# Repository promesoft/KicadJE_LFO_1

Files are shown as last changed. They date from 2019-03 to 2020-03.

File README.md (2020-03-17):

# Johansen Engineering KiCadJE_LFO_1.2 (Rev B)

Analogue LFO - minor adjustments - new jacks (PJ321 -> pj324) - remove Sine Adj

555 Based LFO - minor adjustments - new jacks (PJ321 -> pj324) - remove XXX

NAND - Footprint adj

# Purpose
Fix issues with RevA

## 555 LFO
+/- 10V LFO Square, Triangle, Sine

2 frequency ranges

## LFO
+/- 10V LFO Square, Triangle, Sine

## NAND
NOT Gate (pull dn) - NAND Gate (both pull up) - AND Gate (both pull up)

0-10V output - CMOS input

## D-Flip Flop
0-10V output - CMOS input

## MMX
+-10V Input/output - DC couple

Top - 3 input mixer with phase reversal

Bottom - 3 mult output with phase reversal - uses mixer output as input if not applied to mult input

# Status - In the mail
## Initial 
| Stage  | Detail | Status |
| --- | --- | --- |
| create material  | sch/pcb | OK  |
| | gerber | OK |
| production  | | OK |
|  | produced | Yes |
|  | delivered | OK |

## Preliminary validation
| Test  | Detail | Status |
| --- | --- | --- |
| Initial Inspection | | OK |
| Initial Technical Test | LFO555 |  |
| | | PJ321 should be 1 mm further from the front, center tap works - minor footprint twist in pj324|
| Initial Technical Test | NAND |  |
| | | cut power plane and add 20k across to fix not blowing other units due to hard pull up on tip.
| Initial Product Test | LFO |  |
| Initial Product Test | LFO555 | Sine and Tri not working - needs ac coupling from square - needs dc compensation |
| Initial Product Test | MMX2 | |
| Initial Product Test | NAND | Now working with 4093 - needs pull up resistors and I/O protection |
| Initial Product Test | FlipFlop |  |

## Secondary validation
| Test  | Detail | Status |
| --- | --- |--- |
| Product Test | LFO | |
| Product Test | LFO555 | working right - tri and sine needs tweaking of waveforms |
| Product Test | MMX2 |  |
| Product Test | NAND | working - see issues |
| Product Test | FlipFlop | Working as intended except for LED's |
| Quality | LFO | |
| Quality | LFO555 | |
| Quality | MMX2 | |
| Quality | NAND |  |
| Quality | FlipFlop | |
| Long Term Product Test |  |  |
| Power Draw |  | 

## Errata
### Errata - LFO

### Errata - LFO555

### Errata - MMX2

### Errata - Flip-Flop

### Errata - NAND
Hard pull up to 12 can fry other units !!! Add resistor pull up

Output protection (series resistor?)

## Issues and Notes
### LFO

### 555 LFO
AC coupling of Square should be considered - internal and at least DC adj external

bias current compensation (eg. 10k to GND)

### Flip-Flop

### MMX2
### NAND

# Pictures
## MMX2
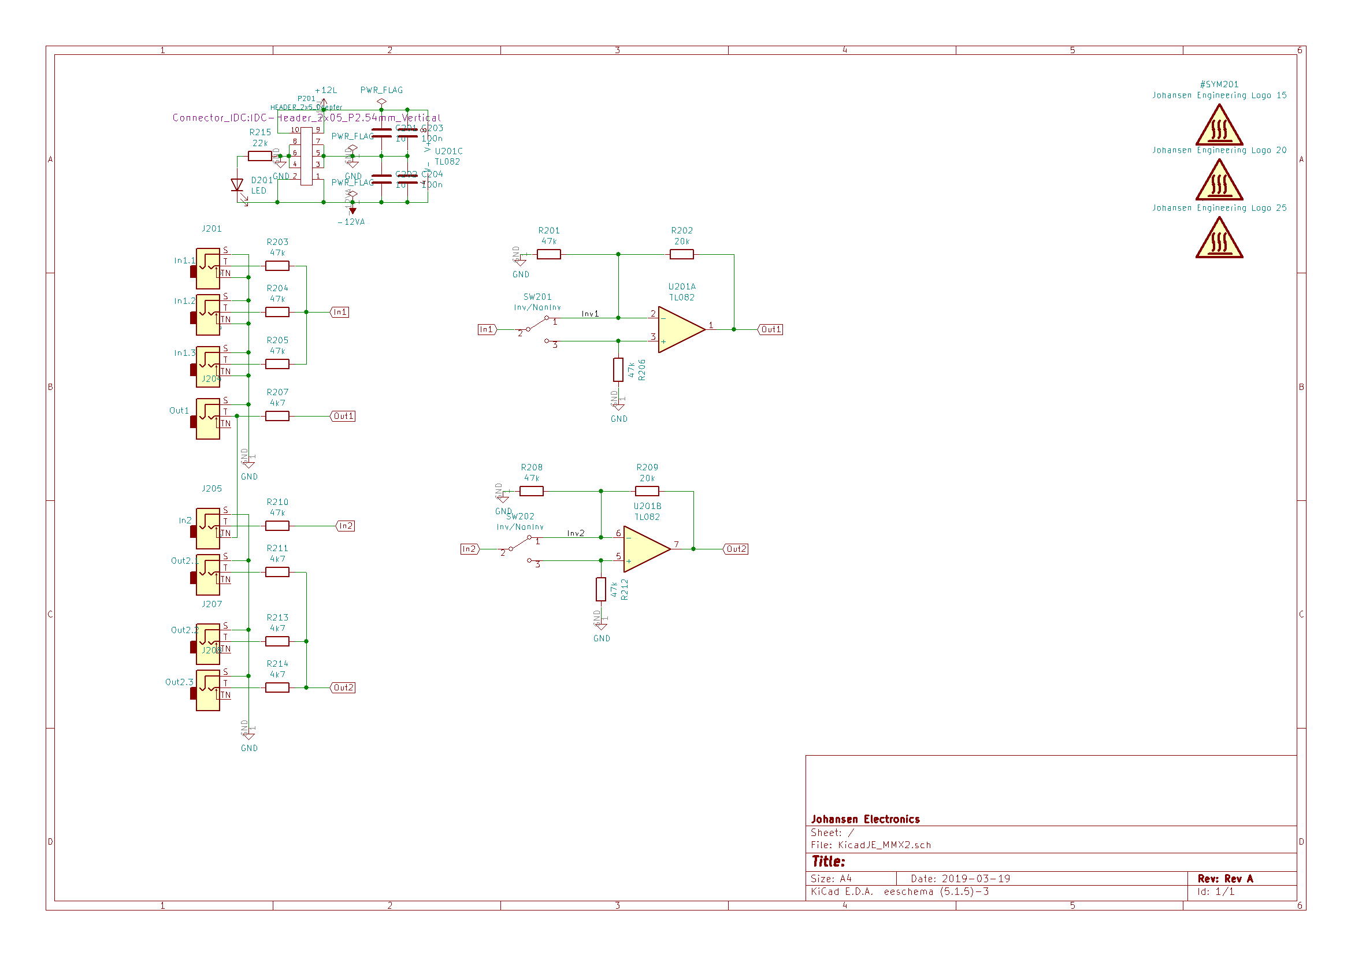
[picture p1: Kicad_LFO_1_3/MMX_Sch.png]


------------------------------------------------
# Johansen Engineering KiCadJE_LFO_1
Initial Analogue LFO

# Purpose

# Status - Evaluated
## Initial 
| Stage  | Detail | Status |
| --- | --- | --- |
| create material  | sch/pcb | OK  |
| | gerber | OK |
| production  | | OK |
|  | produced | Yes |
|  | delivered | Yes |
## Preliminary validation
| Test  | Detail | Status |
| --- | --- | --- |
| Initial Inspection | | OK |
| Initial Technical Test | LFO555 | 555 and 072 gets warm in certain settings |
| Initial Product Test | LFO | Works well with R311 not mounted |
| | | Pot's should be 1 mm closer to front (or jacks further back)|
| Initial Product Test | LFO555 | Sine and Tri not working - RV101B should have 500R series resistor |
| Initial Product Test | MMX2 | Works nicely |
| Initial Product Test | NAND | Not working with 4093 - footprint matches 74HC00 |
| Initial Product Test | FlipFlop | Working |

## Secondary validation
| Test  | Detail | Status |
| --- | --- |--- |
| Product Test | LFO | |
| Product Test | LFO555 | not working right |
| Product Test | MMX2 | Working as intended |
| Product Test | NAND | Will Never work |
| Product Test | FlipFlop | Working as intended except for LED's |
| Quality | LFO | Sounds nice - a few constraints on pot's would be nice|
| Quality | LFO555 | |
| Quality | MMX2 | |
| Quality | NAND | Will Never work |
| Quality | FlipFlop | |
| Long Term Product Test |  |  |
| Power Draw |  | 

## Errata
### Errata - LFO555
1 - SW101 too close to P101
### Errata - MMX2
1 - 1206 caps (C201+C202) are too close to the switch to mount both
### Errata - Flip-Flop
1 - LED positions swapped
### Errata - NAND
Will Never work - Footprint wrong so Input is directly coupled to output for some NAND's

## Issues and Notes
### LFO
1 - 100k should not be mounted (it ruins feedback)

2 - Sine pot should have 2k series resistor

3 - C303 could be 100nF and 1uF addon with a switch for high low

4 - Frequency pot is sensitive at low freq

5 - Chose different Jacks

6 - Consider adding series resistor to outputs

7 - mounting holes

8 - Pot's should be 1 mm closer to front (or jacks further back)

### 555 LFO
1 - RV101B should have series resistor (330 - 1k)

2 - All outputs should have a series resistor (470R ?)

3 - Pot's should be 1 mm closer to front (or jacks further back)

4 - RV101 footprint not matching pots

### Flip-Flop
1 - LED positions swapped

### NAND
Will Never work - Footprint wrong so Input is directly coupled to output for some NAND's

# Pictures
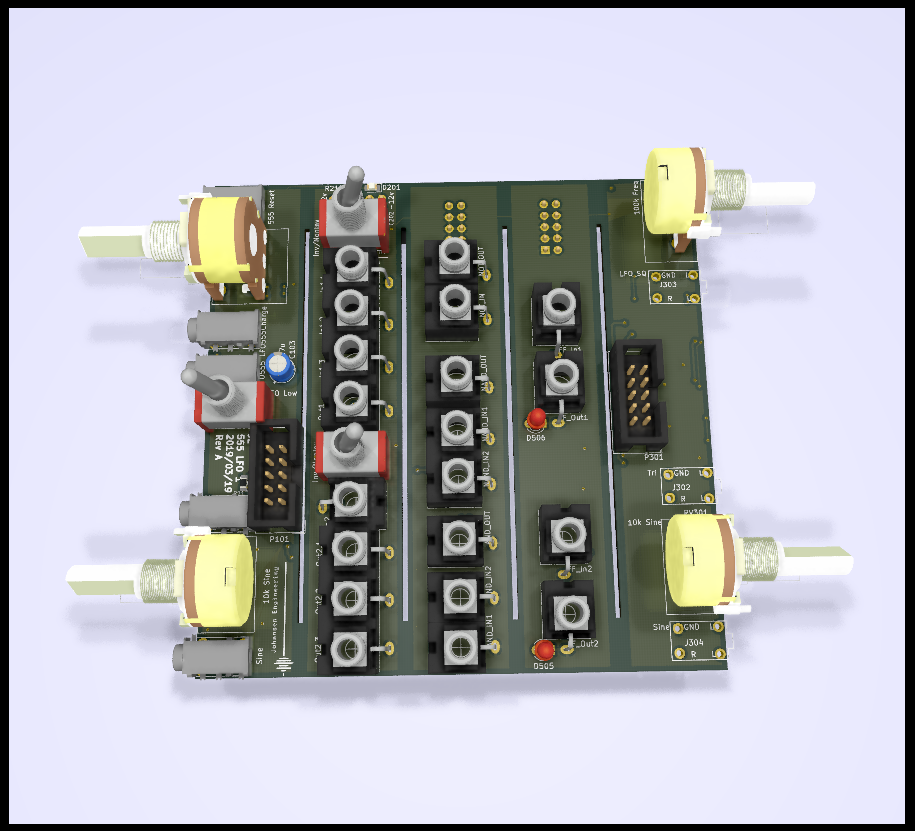
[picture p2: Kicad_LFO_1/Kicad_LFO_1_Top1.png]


# Inspiration from 
https://www.electronics-tutorials.ws/waveforms/555_oscillator.html

http://electro-music.com/forum/topic-31166.html

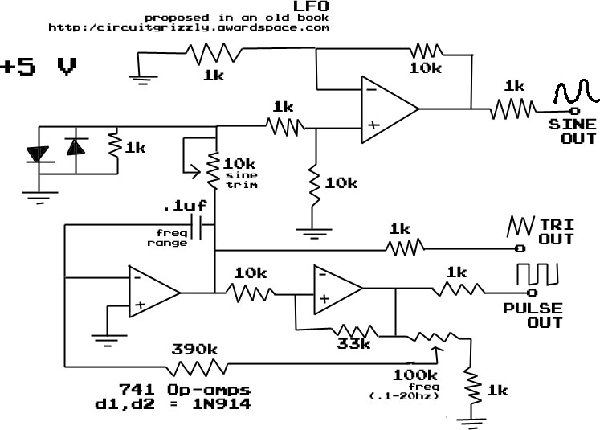
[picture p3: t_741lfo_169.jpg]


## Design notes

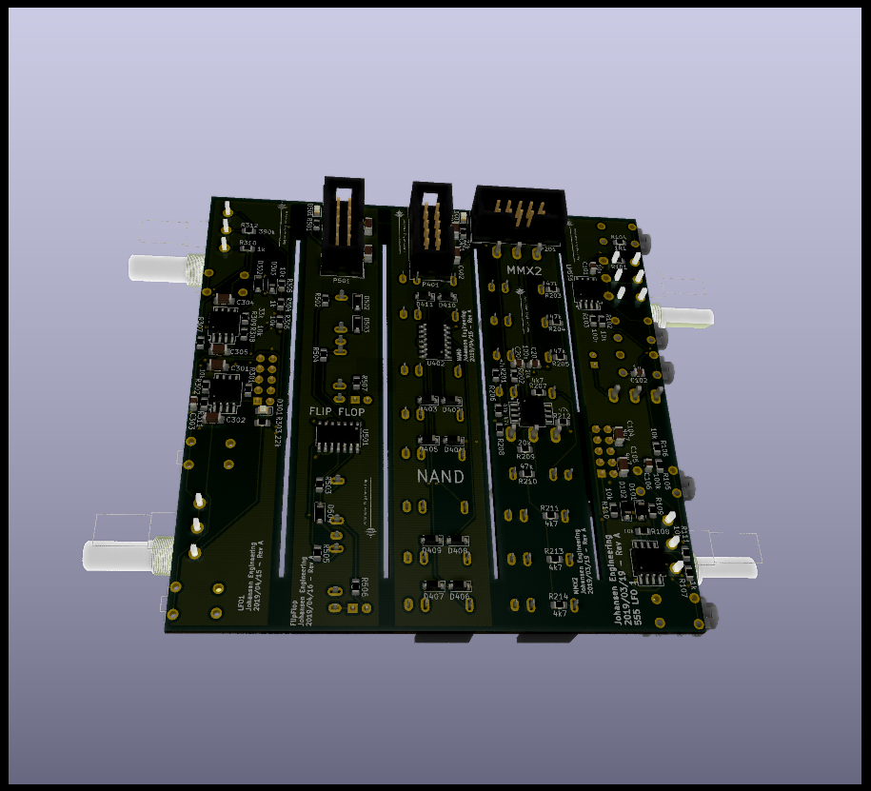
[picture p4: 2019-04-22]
Kicad_LFO_1/Kicad_LFO_1_Bottom1.png

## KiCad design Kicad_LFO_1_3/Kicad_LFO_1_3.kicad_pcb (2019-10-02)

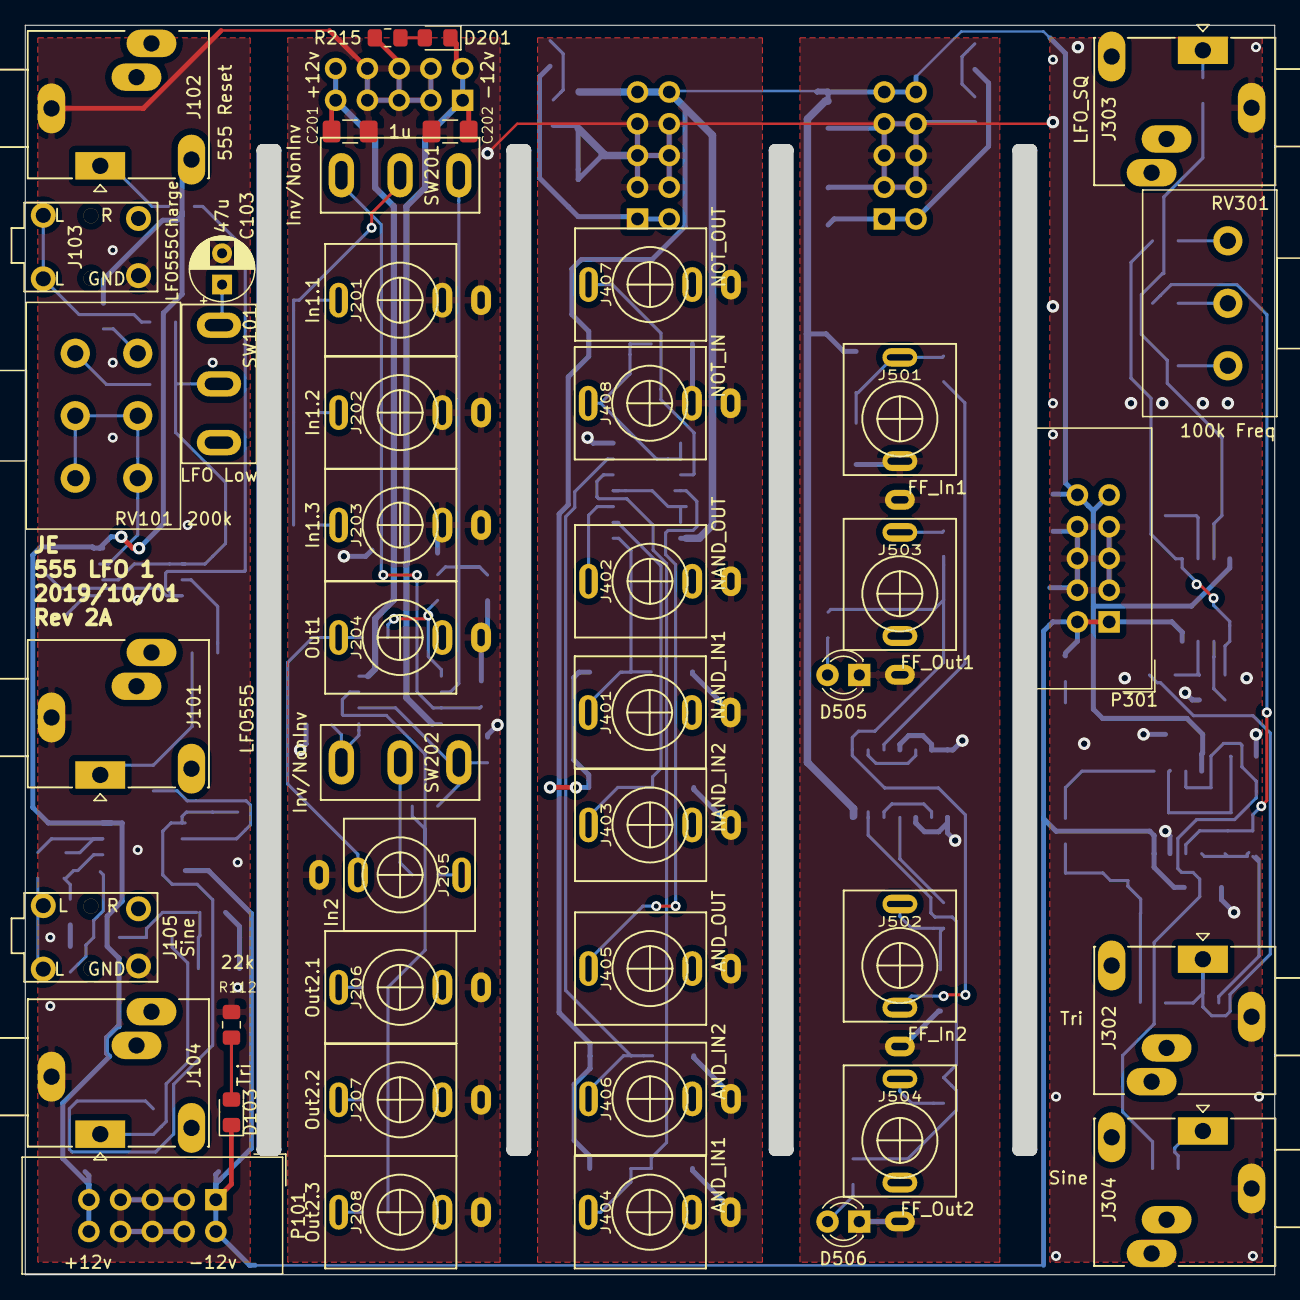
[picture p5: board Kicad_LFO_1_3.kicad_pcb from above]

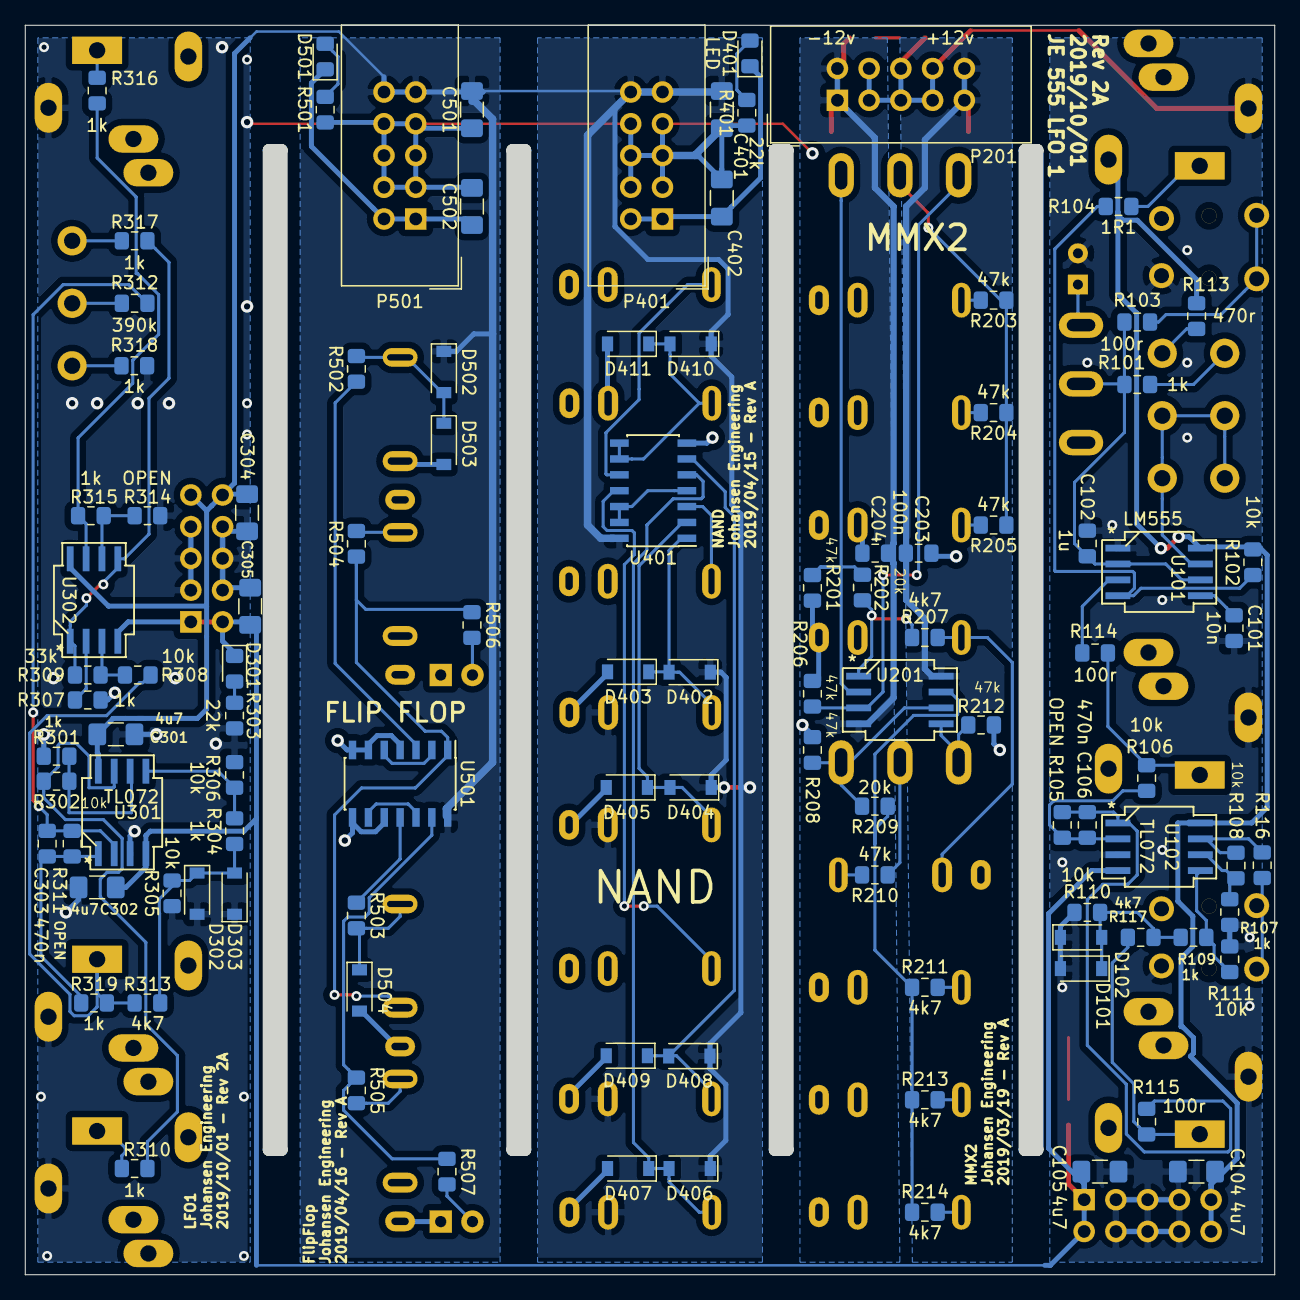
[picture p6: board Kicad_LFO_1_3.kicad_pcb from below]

Board: 2 copper layers, 100.0 x 100.0 mm, 147 parts (103 on the bottom side), 83 nets.

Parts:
C101: 10n; C_0805_2012Metric_Pad1.15x1.40mm_HandSolder
C102: 1u; C_0805_2012Metric_Pad1.15x1.40mm_HandSolder
C103: 47u; CP_Radial_D5.0mm_P2.50mm
C104, C105, C301, C302, C401, C402, C501, C502: 4u7; C_1206_3216Metric_Pad1.42x1.75mm_HandSolder
C106, C303: 470n; C_0805_2012Metric_Pad1.15x1.40mm_HandSolder
C201, C202: 1u; C_1206_3216Metric_Pad1.42x1.75mm_HandSolder
C203, C204: 100n; C_0805_2012Metric_Pad1.15x1.40mm_HandSolder
C304, C305: 100n; C_1206_3216Metric_Pad1.42x1.75mm_HandSolder
D101, D102, D302, D303: 1N4148W; D_SOD-123
D103, D201, D301, D401, D501: LED; LED_0805_2012Metric_Pad1.15x1.40mm_HandSolder
D402, D403, D404, D405, D406, D407, D408, D409, D410, D411, D502, D503, D504: MRA4007T3G; D_SOD-123
D505: LEDOut1; LED_D3.0mm
D506: LEDOut2; LED_D3.0mm
J101: LFO555; Jack_3.5mm_Ledino_KB3SPRS_Horizontal
J102: 555 Reset; Jack_3.5mm_Ledino_KB3SPRS_Horizontal
J103: LFO555Charge; AudioJack3StereoNarrow-PJ-321
J104, J302: Tri; Jack_3.5mm_Ledino_KB3SPRS_Horizontal
J105: Sine; AudioJack3StereoNarrow-PJ-321
J201: In1.1; PJ301SM
J202: In1.2; PJ301SM
J203: In1.3; PJ301SM
J204: Out1; PJ301SM
J205: In2; PJ301SM
J206: Out2.1; PJ301SM
J207: Out2.2; PJ301SM
J208: Out2.3; PJ301SM
J303: LFO_SQ; Jack_3.5mm_Ledino_KB3SPRS_Horizontal
J304: Sine; Jack_3.5mm_Ledino_KB3SPRS_Horizontal
J401: NAND_IN1; PJ301SM
J402: NAND_OUT; PJ301SM
J403: NAND_IN2; PJ301SM
J404: AND_IN1; PJ301SM
J405: AND_OUT; PJ301SM
J406: AND_IN2; PJ301SM
J407: NOT_OUT; PJ301SM
J408: NOT_IN; PJ301SM
J501: FF_In1; PJ301SM
J502: FF_In2; PJ301SM
J503: FF_Out1; PJ301SM
J504: FF_Out2; PJ301SM
P101, P201, P301, P401, P501: HEADER_2x5_Doepfer; IDC-Header_2x05_P2.54mm_Vertical
R101, R107, R109, R301, R304, R307, R310, R315, R316, R317, R318, R319: 1k; R_0805_2012Metric_Pad1.15x1.40mm_HandSolder
R102, R106, R108, R110, R111, R302, R305, R306, R308: 10k; R_0805_2012Metric_Pad1.15x1.40mm_HandSolder
R103, R114, R115, R116: 100r; R_0805_2012Metric_Pad1.15x1.40mm_HandSolder
R104: 1R1; R_0805_2012Metric_Pad1.15x1.40mm_HandSolder
R105, R311, R314: OPEN; R_0805_2012Metric_Pad1.15x1.40mm_HandSolder
R112, R215, R303, R401, R501, R506, R507: 22k; R_0805_2012Metric_Pad1.15x1.40mm_HandSolder
R113: 470r; R_0805_2012Metric_Pad1.15x1.40mm_HandSolder
R117, R207, R211, R213, R214, R313, R502, R503, R504, R505: 4k7; R_0805_2012Metric_Pad1.15x1.40mm_HandSolder
R201, R203, R204, R205, R206, R208, R210, R212: 47k; R_0805_2012Metric_Pad1.15x1.40mm_HandSolder
R202, R209: 20k; R_0805_2012Metric_Pad1.15x1.40mm_HandSolder
R309: 33k; R_0805_2012Metric_Pad1.15x1.40mm_HandSolder
R312: 390k; R_0805_2012Metric_Pad1.15x1.40mm_HandSolder
RV101: 200k; Potentiometer_Alps_RK163_Dual_Horizontal
RV301: 100k Freq; Potentiometer_Alps_RK163_Single_Horizontal
SW101: LFO Low; SP1MS1
SW201, SW202: Inv/NonInv; SP1MS1
U101: LM555; AJ_SO-8_5.3x6.2mm_P1.27mm
U102, U301, U302: TL072; AJ_SO-8_5.3x6.2mm_P1.27mm
U201: TL082; AJ_SO-8_5.3x6.2mm_P1.27mm
U401: 4011; SOIC-14_3.9x8.7mm_P1.27mm
U501: 4013; SOIC-14_3.9x8.7mm_P1.27mm

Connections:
+12L: C201.1, C203.1, P201.9, P201.10, U201.8
+12V: C104.2, C301.2, C304.2, C401.2, C501.2, D402.1, D404.1, D406.1, D408.1, D410.1, D502.1, J102.TN, J401.TN, J403.TN, J404.TN, J406.TN, P101.9, P101.10, P301.9, P301.10, P401.9, P401.10, P501.9, P501.10, R102.2, R113.2, U101.8, U102.8, U301.8, U302.8, U401.14, U501.14
-12V: C105.1, C302.1, C305.1, C402.1, C502.1, D103.1, D301.1, D401.1, D501.1, P101.1, P101.2, P301.1, P301.2, P401.1, P401.2, P501.1, P501.2, U102.4, U301.4, U302.4
-12VA: C202.2, C204.2, D201.1, P201.1, P201.2, U201.4
/KicadJE_MMX2/Inv1: R201.1, R202.2, SW201.1, U201.2
/KicadJE_MMX2/Inv2: R208.1, R209.2, SW202.1, U201.6
AND_IN1: D406.2, D407.1, J404.T, U401.5
AND_IN2: D408.2, D409.1, J406.T, U401.6
Charge: J103.T, R103.1
FF_IN1: R502.1, U501.3
FF_IN2: R503.1, U501.11
FF_OUT1: J502.TN, R504.1, R506.1, U501.1
FF_OUT2: R505.1, R507.1, U501.13
GND: C101.2, C102.2, C103.2, C104.1, C105.2, C201.2, C202.1, C203.2, C204.1, C301.1, C302.2, C304.1, C305.2, C401.1, C402.2, C501.1, C502.2, D101.2, D102.1, D302.2, D303.1, D403.2, D405.2, D407.2, D409.2, D411.2, D503.2, D504.2, D505.1, D506.1, J101.S, J102.S, J103.S, J104.S, J105.S, J201.S, J201.TN, J202.S, J202.TN, J203.S, J203.TN, J204.S, J205.S, J206.S, J207.S, J208.S, J302.S, J303.S, J304.S, J401.S, J402.S, J403.S, J404.S, J405.S, J406.S, J407.S, J408.S, J408.TN, J501.S, J501.TN, J502.S, J503.S, J504.S, P101.3, P101.4, P101.5, P101.6, P101.7, P101.8, P201.3, P201.4, P201.5, P201.6, P201.7, P201.8, P301.3, P301.4, P301.5, P301.6, P301.7, P301.8, P401.3, P401.4, P401.5, P401.6, P401.7, P401.8, P501.3, P501.4, P501.5, P501.6, P501.7, P501.8, R107.1, R110.1, R111.1, R112.1, R201.2, R206.1, R208.2, R212.1, R215.1, R301.1, R303.1, R305.1, R306.1, R307.1, R314.1, R318.2, R401.1, R501.1, U101.1, U102.3, U301.3, U401.7, U501.4, U501.6, U501.7, U501.8, U501.10
In1: R203.1, R204.1, R205.1, SW201.2
In2: R210.1, SW202.2
NAND_IN1: D402.2, D403.1, J401.T, U401.1
NAND_IN2: D404.2, D405.1, J403.T, U401.2
NOT_IN: D410.2, D411.1, J408.T, U401.8, U401.9
unnamed: C101.1, U101.5
unnamed: C102.1, R101.2, R103.2, SW101.2, U101.2, U101.6
unnamed: C103.1, SW101.3
unnamed: C106.1, R105.2, R115.2, U102.1
unnamed: C106.2, R105.1, R106.2, U102.2
unnamed: C303.1, R311.2, R319.1, U301.1
unnamed: C303.2, R311.1, R312.2, U301.2
unnamed: D101.1, D102.2, R109.1, R110.2, R117.2
unnamed: D103.2, R112.2
unnamed: D201.2, R215.2
unnamed: D301.2, R303.2
unnamed: D302.1, D303.2, R304.1, R305.2, R313.2
unnamed: D401.2, R401.2
unnamed: D501.2, R501.2
unnamed: D502.2, D503.1, J501.T, R502.2
unnamed: D504.1, J502.T, R503.2
unnamed: D505.2, R506.2
unnamed: D506.2, R507.2
unnamed: J201.T, R203.2
unnamed: J202.T, R204.2
unnamed: J203.T, R205.2
unnamed: J204.T, J205.TN, R207.2
unnamed: J205.T, R210.2
unnamed: J206.T, R211.2
unnamed: J207.T, R213.2
unnamed: J208.T, R214.2
unnamed: J402.T, U401.3
unnamed: J405.T, U401.11
unnamed: J407.T, U401.10
unnamed: J503.T, R504.2
unnamed: J504.T, R505.2
unnamed: R101.1, RV101.1
unnamed: R102.1, R104.1, U101.4
unnamed: R107.2, R108.1, U102.6
unnamed: R108.2, R116.2, U102.7
unnamed: R109.2, R111.2, U102.5
unnamed: R113.1, RV101.4
unnamed: R114.2, U101.3
unnamed: R206.2, SW201.3, U201.3
unnamed: R212.2, SW202.3, U201.5
unnamed: R301.2, R302.1, U301.6
unnamed: R302.2, R310.1, U301.7
unnamed: R304.2, R306.2, U301.5
unnamed: R307.2, U302.2
unnamed: R308.2, R309.1, U302.3
unnamed: R309.2, R317.1, U302.1, U302.5
unnamed: R314.2, R315.1, U302.6
unnamed: R315.2, R316.1, U302.7
unnamed: R317.2, RV301.3
unnamed: R318.1, RV301.1
unnamed: RV101.2, RV101.3, RV101.5, RV101.6, U101.7
unnamed: U401.4, U401.12, U401.13
unnamed: U501.2, U501.5
unnamed: U501.9, U501.12
Out1: R202.1, R207.1, U201.1
Out2: R209.1, R211.1, R213.1, R214.1, U201.7
Reset: J102.T, R104.2
Sine: J105.T, R116.1
Sine3: J304.T, R310.2
Square: J101.T, R106.1, R114.1
Square3: J303.T, R316.2
Square3fb: R312.1, RV301.2
Tri: J104.T, R115.1, R117.1
Tri3: J302.T, R308.1, R313.1, R319.2

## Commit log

2019-03-16 Inspiration and upd SCH 555
    [_saved_Kicad_LFO_1.sch]
2019-03-18 Init PCB
    [Kicad_LFO_1.kicad_pcb, Kicad_LFO_1.sch, _saved_Kicad_LFO_1.sch]
2019-03-18 Op amp and IDC power
    [Kicad_LFO_1.sch]
2019-03-18 Sine and tri integrator added
    [Kicad_LFO_1.kicad_pcb, Kicad_LFO_1.sch]
2019-03-18 Update Kicad_LFO_1.sch
    footprints and caps
    [Kicad_LFO_1.sch]
2019-03-19 Routed 555 LFO
    [Kicad_LFO_1.kicad_pcb]
2019-03-19 Update Kicad_LFO_1.kicad_pcb
    3D
    [Kicad_LFO_1.kicad_pcb]
2019-03-19 PCB bottom layer Vcc
    [Kicad_LFO_1.kicad_pcb]
2019-03-19 Power LED and MMX2
    [KicadJE_MMX2.sch, Kicad_LFO_1.sch]
2019-03-19 sheet naming
    [KicadJE_MMX2.sch, Kicad_LFO_1.sch]
2019-03-19 2x GND on MMX2
    [KicadJE_MMX2.sch]
2019-03-19 Power settings + Inv net
    [Kicad_LFO_1.kicad_pcb]
2019-03-19 cleanup and decoupl
    [KicadJE_MMX2.sch, Kicad_LFO_1.kicad_pcb]
2019-03-19 Logo - again
    [Kicad_LFO_1.kicad_pcb, _saved_KicadJE_MMX2.sch]
2019-03-19 MMX2 upd
    [KicadJE_MMX2.sch, _saved_KicadJE_MMX2.sch]
2019-03-20 OpAmp LFO added
    [KicadJE_072LFO.sch, KicadJE_MMX2.sch, Kicad_LFO_1.sch]
2019-03-21 TL072 LFO on PCB
    [KicadJE_072LFO.sch, Kicad_LFO_1.kicad_pcb]
2019-04-15 Diode protection
    [KicadJE_NAND.sch]
2019-04-15 U401 remove
    [KicadJE_NAND.sch, Kicad_LFO_1.kicad_pcb]
2019-04-15 OpAmp LFO components placed
    [Kicad_LFO_1.kicad_pcb]
2019-04-16 FF Sch done 1
    [KicadJE_072LFO.sch, KicadJE_FlipFlop.sch, KicadJE_MMX2.sch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]
2019-04-16 Annotate
    Annotate
    [KicadJE_FlipFlop.sch]
2019-04-16 THT Placed
    [KicadJE_FlipFlop.sch, Kicad_LFO_1.kicad_pcb]
2019-04-16 LED Out
    [KicadJE_FlipFlop.sch]
2019-04-16 SMD Placed
    [Kicad_LFO_1.kicad_pcb]
2019-04-16 Copper plane
    [Kicad_LFO_1.kicad_pcb]
2019-04-22 BOM created
2019-04-22 NAND/AND TN to +12V default
    to enable buffer/inverter mode with only one input
    [KicadJE_NAND.sch]
2019-04-22 RevB PCB
    [Kicad_LFO_1-B_Cu.gbr, Kicad_LFO_1-B_Mask.gbr, Kicad_LFO_1-B_Paste.gbr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]
2019-06-03 Second edition prepared
    [KicadJE_072LFO.sch, KicadJE_FlipFlop.sch, KicadJE_MMX2.sch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]
2019-06-03 LED's swapped for flip flop
    [Kicad_LFO_1_2.kicad_pcb]
2019-10-01 Fixing Errata from rev 1B
    [KicadJE_072LFO.sch, KicadJE_FlipFlop.sch, KicadJE_MMX2.sch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]
2019-10-01 Fixing LFO Errata
    [KicadJE_072LFO.sch, Kicad_LFO_1_2.sch]
2019-10-01 Jack footprints changed to Connector_Audio:Jack_3.5mm_Ledino_KB3SPRS_Horizontal
    [Kicad_LFO_1_2.sch]
2019-10-01 Annotate Rev 2A
    [KicadJE_072LFO.sch, KicadJE_NAND.sch, Kicad_LFO_1_2.sch]
2019-10-01 footprint adj Rev 2A
    [KicadJE_072LFO.sch, KicadJE_NAND.sch]
2019-10-01 LFO 1 Routed and labeled
    [Kicad_LFO_1_2.kicad_pcb]
2019-10-01 Jack PJ321 for some
    [Kicad_LFO_1_2.sch]
2019-10-01 LFO 555 done
    [Kicad_LFO_1_2.kicad_pcb, _saved_Kicad_LFO_1_2.sch]
2019-10-02 Jack footprint
    [Kicad_LFO_1_2.sch, _saved_Kicad_LFO_1_2.sch]
2020-02-15 rev 1.3
    [KicadJE_072LFO.sch, KicadJE_FlipFlop.sch, KicadJE_MMX2.sch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]
2020-02-16 NAND - resistor out
    [KicadJE_NAND.sch]
2020-02-16 LFO AC Couple Square
    [Kicad_LFO_1_3.sch]
2020-02-16 FF - Fix LED dimm issue
    [KicadJE_FlipFlop.sch]
2020-02-16 Update KicadJE_NAND.sch
    Pull up +12V added resistors to avoid burning outputs upon connection
    [KicadJE_NAND.sch]
2020-02-17 nand sch
    [KicadJE_NAND.sch, Kicad_LFO_1_3.sch]
